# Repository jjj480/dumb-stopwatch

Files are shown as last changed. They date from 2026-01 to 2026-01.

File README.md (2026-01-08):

# dumb-stopwatch
its a stopwatch without a microcontroller only with ics. The time displayed on 4 7 Segment displays and goes up one hour.

i wanted to try some othor method to electric things than with a microcontroller. And found that a stoppwatch is not to dificult





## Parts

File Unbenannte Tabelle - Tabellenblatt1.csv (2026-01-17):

name | Link | unitprice | amount | price | Description
PCB |  | 8,21 | 5 | 16,93
3d printed case
7 segment display | https://www.mouser.de/ProductDetail/Broadcom-Avago/HDSP-7401?qs=pQfy5%252BKCabKcASjs00IdeQ%3D%3D | 2,99 | 4 | 11,96
595-NA555P | https://www.mouser.de/ProductDetail/Texas-Instruments/NA555P?qs=iSMark9AYDXSJ%2FEUL8JKyA%3D%3D | 35 | 1 | 0,35
595-CD4013B | https://www.mouser.de/ProductDetail/Texas-Instruments/CD4013BE?qs=pt%2FIv5r0EPc2Chv9B9JKAA%3D%3D | 0,59 | 1 | 0,59
595-CD4081BE | https://www.mouser.de/ProductDetail/Texas-Instruments/CD4081BE?qs=dQbkqP7qjaZ0jSz5I7zHYA%3D%3D | 0,88 | 1 | 0,88
595-CD4026BE | https://www.mouser.de/ProductDetail/Texas-Instruments/CD4026BE?qs=bkMXpVdiF42nXhwyXNpecA%3D%3D | 1,05 | 4 | 4,2
Diode |  |  | 1 |  | i allready have some
switches |  |  | 2 |  | i allready have some
10kOhm resistor | https://de.aliexpress.com/item/1005008175194639.html?curPageLogUid=9wPGT0fVvwnQ | 0,99 |  | 0,99
680kOhm restistor | https://de.aliexpress.com/item/1005008175194639.html?curPageLogUid=9wPGT0fVvwnQ | 0,99 |  | 0,99
300Ohm resistor | https://www.amazon.de/YOKIVE-Kohlenstoff-Widerst%C3%A4nde-Toleranzen-Elektronische/dp/B0BNHTXS1S | 5,09 |  | 5,09
battery enclosure | https://de.aliexpress.com/item/1005005565467844.html?curPageLogUid=h7oGt9CShYqs | 1,95 | 1 | 1,95
1uf kondensator | https://de.aliexpress.com/item/1005006127941473.html?curPageLogUid=MahyPvrV7xL2 |  | 1 | 1,49
100 uf kondensator | https://www.amazon.de/63V-100uf-Kondensator-Radialelektrolytische-Kondensatoren/dp/B0FDQKKKFM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 |  | 7 | 0,99
 |  |  | Gesamt | 46,41

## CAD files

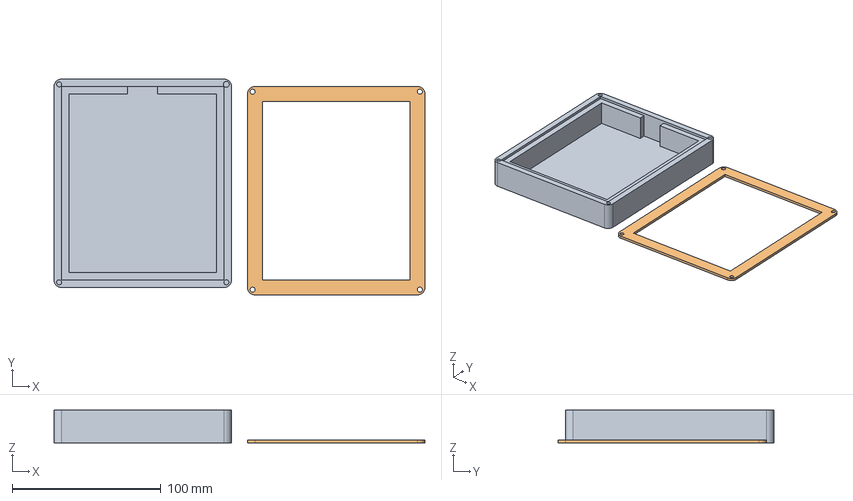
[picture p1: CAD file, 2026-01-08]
CAD/stopuhr gehäuse (1).step
249.3 x 145.0 x 22.0 mm
R_Axial_DIN0207_L6.3mm_D2.5mm_P7.62mm_Horizontal x 32
CP_Radial_D5.0mm_P2.00mm x 10
PinSocket_1x01_P2.54mm_Vertical x 2
DIP-8_W7.62mm
HDSP-7401 x 4
D_DO-41_SOD81_P10.16mm_Horizontal
stopuhr_PCB

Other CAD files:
CAD/stopuhr gehäuse.f3d

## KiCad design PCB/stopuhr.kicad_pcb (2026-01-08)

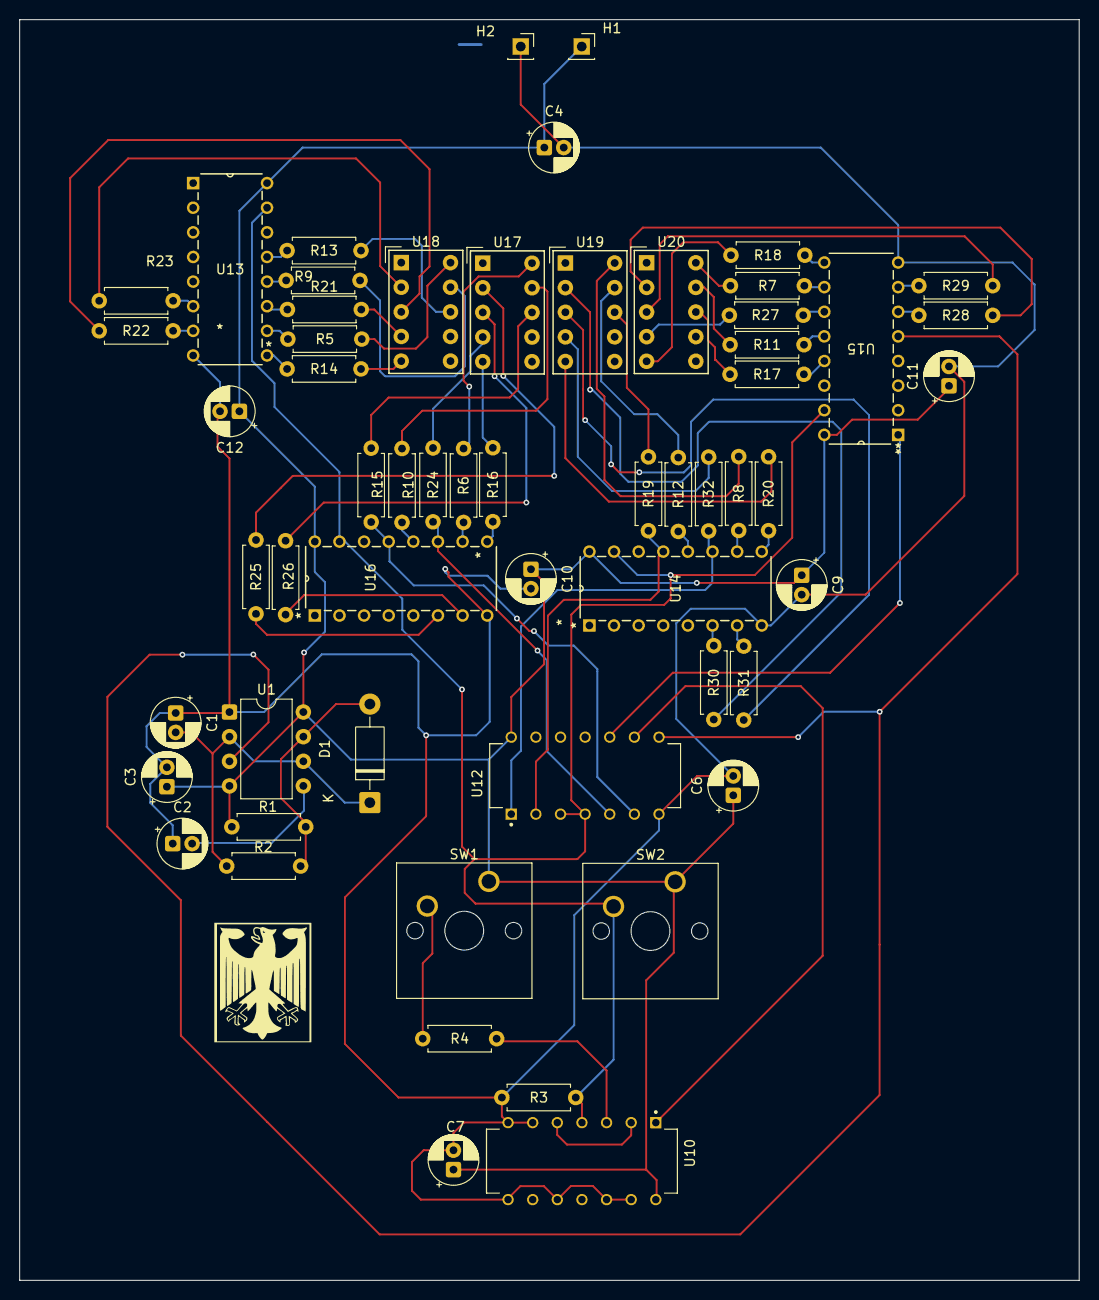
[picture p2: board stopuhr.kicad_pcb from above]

Board: 2 copper layers, 109.3 x 130.0 mm, 58 parts (0 on the bottom side), 68 nets.

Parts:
C1: 1uf; CP_Radial_D5.0mm_P2.00mm
C2: 10nf; CP_Radial_D5.0mm_P2.00mm
C3, C4, C6, C7, C9, C10, C11, C12: 100nf; CP_Radial_D5.0mm_P2.00mm
D1: SB160; D_DO-41_SOD81_P10.16mm_Horizontal
H1, H2: MountingHole_Pad; PinSocket_1x01_P2.54mm_Vertical
R1: 680KO; R_Axial_DIN0207_L6.3mm_D2.5mm_P7.62mm_Horizontal
R2, R3, R4: 10kO; R_Axial_DIN0207_L6.3mm_D2.5mm_P7.62mm_Horizontal
R5, R6, R7, R8, R9, R10, R11, R12, R13, R14, R15, R16, R17, R18, R19, R20, R21, R22, R23, R24, R25, R26, R27, R28, R29, R30, R31, R32: 300O; R_Axial_DIN0207_L6.3mm_D2.5mm_P7.62mm_Horizontal
SW1: Start/stopp; SW_Cherry_MX_1.00u_PCB
SW2: Reset; SW_Cherry_MX_1.00u_PCB
U1: NA555P; DIP-8_W7.62mm
U10: CD4013BE; DIP794W45P254L1969H508Q14
U12: CD4081BE; DIP794W45P254L1969H508Q14
U13, U14, U15, U16: CD4026BE; N16
U17, U18, U19, U20: HDSP-7401

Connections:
6,1: R32.1, U12.1 (A), U14.11 (E)
6,2: R19.1, U12.2 (B), U14.13 (C)
6,r: R3.1, SW2.2, U10.4 (RESET1), U12.3 (J=A.B), U12.4 (K=C.D), U13.15 (RESET), U14.15 (RESET), U15.15 (RESET), U16.15 (RESET)
60,1: R24.1, U12.5 (C), U16.11 (E)
60,2: R15.1, U12.6 (D), U16.13 (C)
+5V: C3.1, C4.1, C6.1, C7.1, C9.1, C10.1, C11.1, C12.1, H1.1, R1.1, SW1.1, SW2.1, U1.4 (R), U1.8 (VCC), U10.14 (VDD), U12.14 (VDD), U13.16 (VDD), U14.16 (VDD), U15.16 (VDD), U16.16 (VDD)
GND: C1.1, C2.1, C3.2, C4.2, C6.2, C7.2, C9.2, C10.2, C11.2, C12.2, H2.1, R3.2, U1.1 (GND), U10.6 (SET1), U10.7 (VSS), U10.8 (SET2), U10.10 (RESET2), U10.12 (~Q2), U10.13 (Q2), U12.7 (VSS), U13.8 (VSS), U14.8 (VSS), U15.8 (VSS), U16.8 (VSS)
unnamed: D1.2 (A), R1.2, R2.2, U1.7 (DIS)
unnamed: C1.2, D1.1 (K), R2.1, U1.2 (TR), U1.6 (THR)
unnamed: R4.2, SW1.2
unnamed: C2.2, U1.5 (CV)
unnamed: R4.1, U10.3 (CLOCK1)
unnamed: U10.2 (~Q1), U10.5 (D1)
unnamed: R5.1, U13.10 (A)
unnamed: R9.1, U13.12 (B)
unnamed: R13.1, U13.13 (C)
unnamed: R14.1, U13.9 (D)
unnamed: R21.1, U13.11 (E)
unnamed: R23.1, U13.6 (F)
unnamed: R22.1, U13.7 (G)
unnamed: R8.1, U14.10 (A)
unnamed: R12.1, U14.12 (B)
unnamed: R20.1, U14.9 (D)
unnamed: R30.1, U14.6 (F)
unnamed: R31.1, U14.7 (G)
unnamed: R7.1, U15.10 (A)
unnamed: R11.1, U15.12 (B)
unnamed: R17.1, U15.13 (C)
unnamed: R18.1, U15.9 (D)
unnamed: R27.1, U15.11 (E)
unnamed: R28.1, U15.6 (F)
unnamed: R29.1, U15.7 (G)
unnamed: R6.1, U16.10 (A)
unnamed: R10.1, U16.12 (B)
unnamed: R16.1, U16.9 (D)
unnamed: R25.1, U16.6 (F)
unnamed: R26.1, U16.7 (G)
unnamed: R6.2, U17.10 (A)
unnamed: R10.2, U17.9 (B)
unnamed: R15.2, U17.8 (C)
unnamed: R16.2, U17.5 (D)
unnamed: R24.2, U17.4 (E)
unnamed: R25.2, U17.2 (F)
unnamed: R26.2, U17.3 (G)
unnamed: R5.2, U18.10 (A)
unnamed: R9.2, U18.9 (B)
unnamed: R13.2, U18.8 (C)
unnamed: R14.2, U18.5 (D)
unnamed: R21.2, U18.4 (E)
unnamed: R23.2, U18.2 (F)
unnamed: R22.2, U18.3 (G)
unnamed: R8.2, U19.10 (A)
unnamed: R12.2, U19.9 (B)
unnamed: R19.2, U19.8 (C)
unnamed: R20.2, U19.5 (D)
unnamed: R32.2, U19.4 (E)
unnamed: R30.2, U19.2 (F)
unnamed: R31.2, U19.3 (G)
unnamed: R7.2, U20.10 (A)
unnamed: R11.2, U20.9 (B)
unnamed: R17.2, U20.8 (C)
unnamed: R18.2, U20.5 (D)
unnamed: R27.2, U20.4 (E)
unnamed: R28.2, U20.2 (F)
unnamed: R29.2, U20.3 (G)
Out: U1.3 (Q), U12.8 (E), U15.5 (CARRY_OUT)
Q: U10.1 (Q1), U12.9 (F)
signal 1: U12.10 (L=E.F), U15.1 (CLK)
